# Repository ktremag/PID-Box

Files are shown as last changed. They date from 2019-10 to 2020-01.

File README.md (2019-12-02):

# PID Box Process
## Our Design 
In order to complete our PID box, we wanted to utilize cardboard in order to make a smooth, friction fit device that we could minimize the size of and make into a slim as possible device. 

## Important Information on Design 
In order to make our box out of cardboard, some adjustments were necessary in the design process. 

### Adjustments 
We chose to use single thickness rather than double corregated cardboard. When cutting with cardboard, it is important to remember that the laser cutter will burn off some of the material so the CAD files must be adjusted for this by measuring kerf (or how much the laser cutter takes off) and adding this value to all of the sides to ensure a tight fit on the final box.

We had to keep in mind that the CAD files adjusted with Kerf will not mate together in a Solidworks assembly very smoothly so extra precautions had to be made so that the lack of an accurate assembly didn't result in mis-measured or mis-fit parts. 

### Using the Laser Cutter With Cardboard 
The laser cutter now has a trial cardboard setting under Natural -> Cardboard -> Test. Because cardboard does burn, it creates smoke and needs to be carefully attended during cutting. This smoke/ash also has the ability to collect on the lens so when cutting a lot of cardboard, be even more careful and if you think that too many particles have collectted on the lens, contact Shields or another teacher so that they may remove and clean it. 

### Measuring Kerf
To measure kerf, a small rectange was laser cut out of our desired cardboard and the length measured (l), next we made another cut down the middle of that rectangle, placed the pieces together and measured the new length(l'). Kerf could then be calculated as (l-l'). 

### Friction Fit
Rather than using the traditional T-cuts that are utilized with Acrylic and other hard materials, cardboard is more effective if it is held together using a friction fit design or a design that does not utilize screws to hold the box together and rather the inherent properties of the cardboard. Our box design uses puzzle-piece esq sides with tabs that connect together. We used the configurations tool to make all the separate sides and created the tabs so that they would be the thickness of the cardboard plus kerf. 

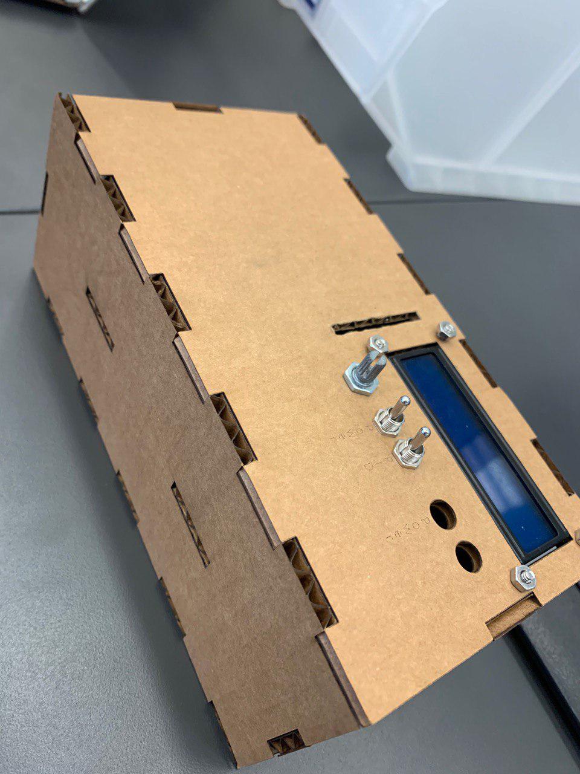
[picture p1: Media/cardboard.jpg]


# PID Box Planning

We will create a box with a spinning wheel powered by a DC motor, an arduino and potentiometer, monitored with a photointerrupter that will display rotations per minute and correct for error using a proportional-integral-derivative controller. Additionally, we would like to minimize wasted materials and use cardboard rather than acrylic as well as a friction fit design. 

## Schedule
We hope to finish this project by December 6th, our weekly milestones and deadlines may be found on our Google Calendar

__Coding and Wiring Process:__ Spin a wheel >> read a wheel speed >> control wheel speed >> implement PID control of wheel speed >> add LEDs, indicators etc. >> Streamline code and wiring

__Solidworks/CAD:__ Determine kerf of cardboard material >> Design box skeleton >> Fricton fit w/ cardboard >> Integrating specific parts/devices >> assemble w/ parts in CAD >> work on actual cardboard etching etc. in order to not look like trash. 

Additionally, we will design/cut a wheel out of acrylic early on in the project so that the code may be fine tuned to the actual goal.

In general, CAD will be up to Frank while coding, wiring and git will be handled by Kit.
## Weekly Milestones

December 6 - Frank: finish updating the midplate & add things for mounting breadboard, Kit: begin to implement PID
December 13 - Frank: finishing touches + motor mount for bok, Kit: calibrate PID and add switches + leds
December 16 - Assemble final and modify for efficiency 

## Criteria and Constraints 
We would like to minimize the total size of our box in order to make it more handheld rather than large and bulky. Additonally, we are attempting a box made of cardboard which complicates the design process somewhat as making cardboard not look unattractive will be an obstacle. Cable/wire placement will likewise need to be managed as minimizing total volume of the box will necessitate more organized wires for functionality.

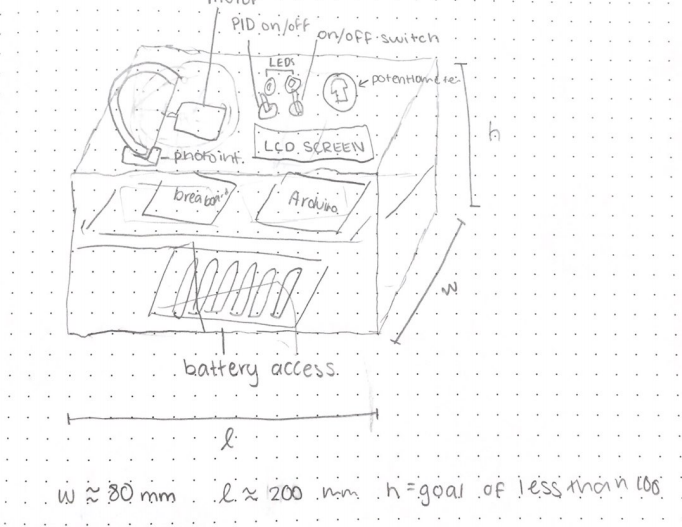
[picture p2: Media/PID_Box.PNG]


## Materials
We expect the necessary materials to be: 
- cardboard for box structure 
- acyrilic wheel
- 3D printed or acrylic breadboard/arduino mount
- battery pack
- arduino uno
- breadboard
- DC motor
- on/off switch
- panel-mounted potentiometer
- LEDs
- LCD screen
- photointerrupter

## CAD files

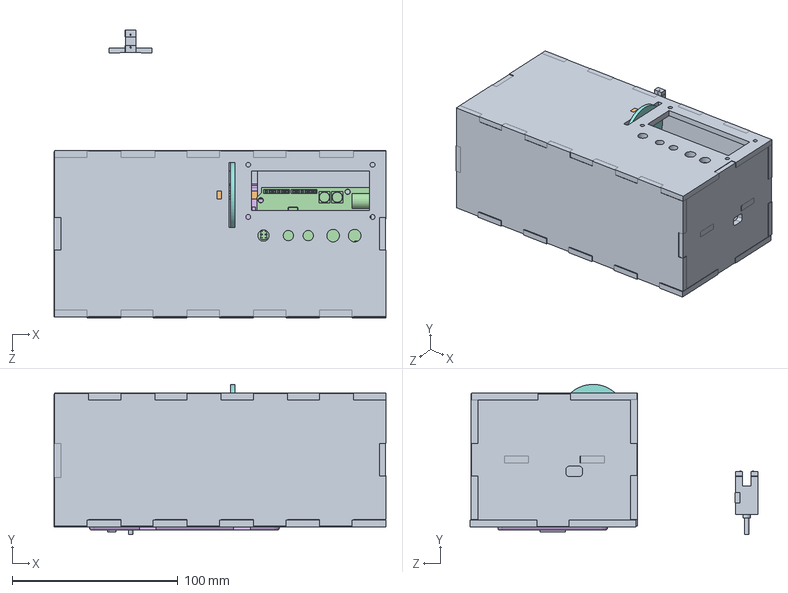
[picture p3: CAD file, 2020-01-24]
CAD/pid_assembly.SLDASM
200.3 x 90.6 x 173.6 mm
PID_box_sides x 7
DC_motor_keyhole_test
breadboard_attachment x 2
ArduinoUno
Half Breadboard
6AA Battery Holder
DCmotor-Size130
Wheel
EE-SX672WR

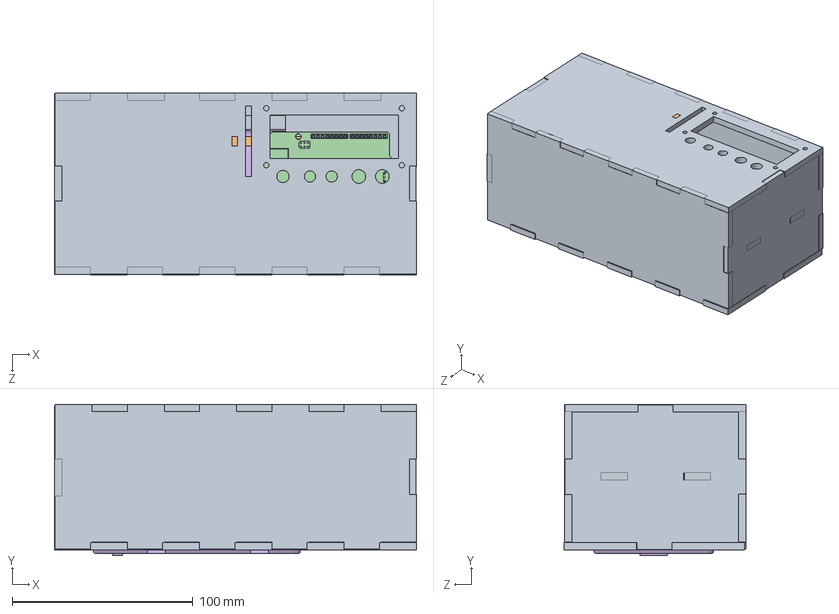
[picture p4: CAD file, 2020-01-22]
CAD/you left your computer on (mrH).SLDASM
200.3 x 83.8 x 101.0 mm
PID_box_sides x 6
DC_motor_keyhole_test
breadboard_attachment x 2
ArduinoUno
Half Breadboard
6AA Battery Holder

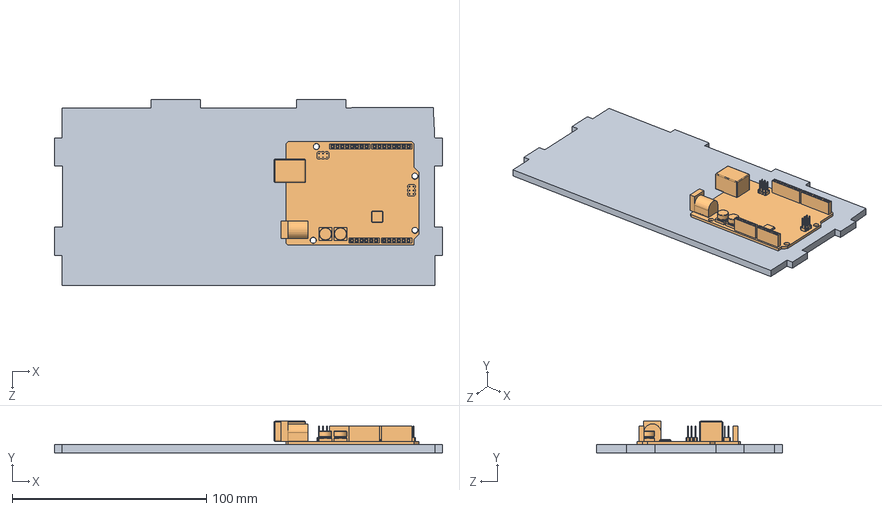
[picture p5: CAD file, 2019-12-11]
CAD/MidPlate_Assem.SLDASM
200.0 x 16.2 x 95.8 mm
PID_box_sides
ArduinoUno

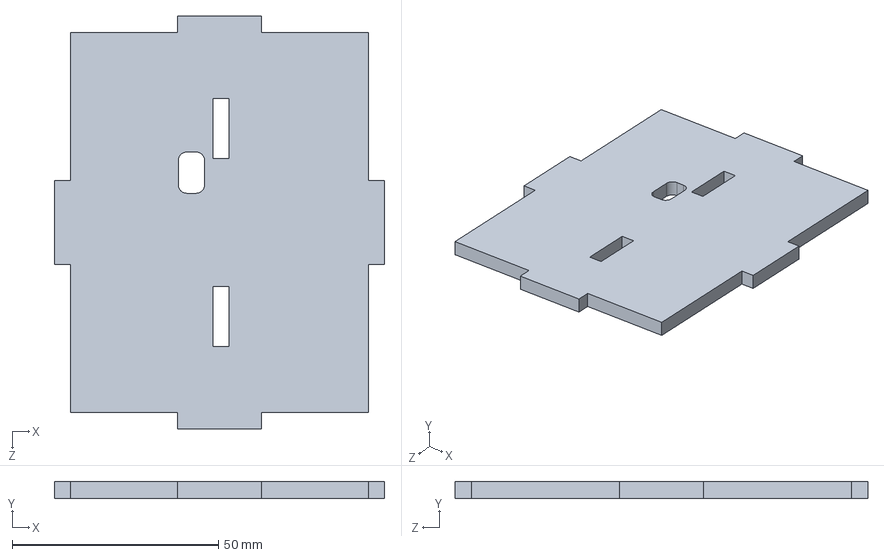
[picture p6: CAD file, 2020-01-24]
CAD/PID_box_sides.SLDPRT
80.0 x 4.15 x 100.0 mm

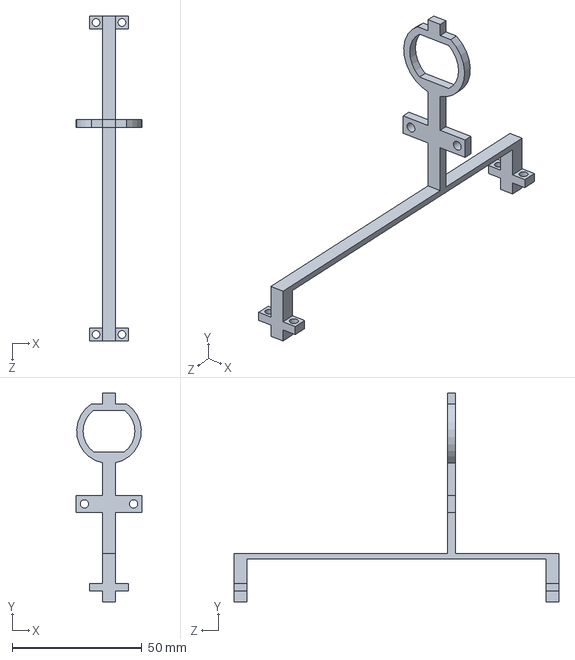
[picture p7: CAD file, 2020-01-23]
CAD/DC_motor_keyhole_test.SLDPRT
25.4 x 80.6 x 125.5 mm

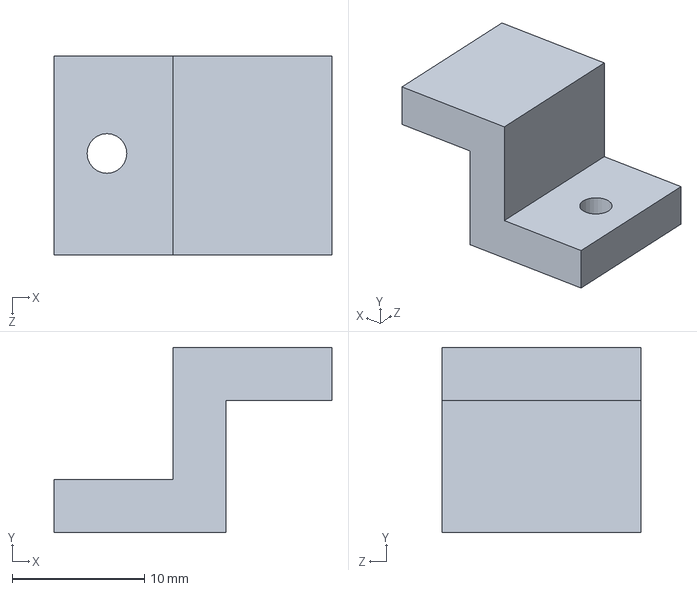
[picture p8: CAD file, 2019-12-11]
CAD/breadboard_attachment.SLDPRT
21.0 x 14.0 x 15.0 mm

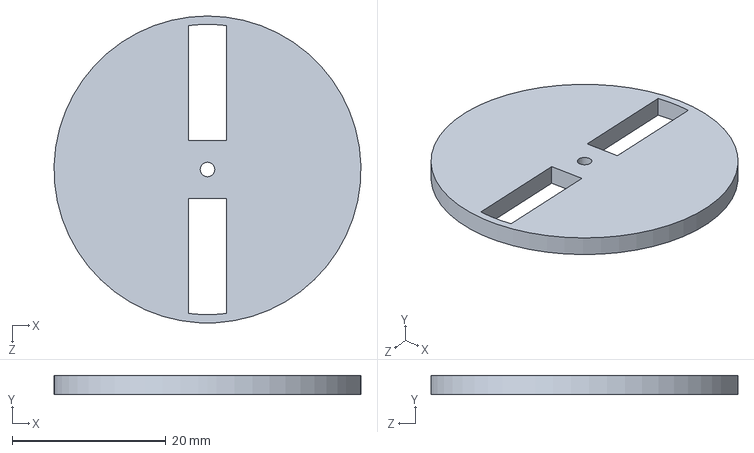
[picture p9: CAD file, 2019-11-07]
CAD/Wheel.SLDPRT
40.0 x 2.50 x 40.0 mm

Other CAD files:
CAD/Fixingswitchholes.SLDDRW
CAD/TopBottomMid.SLDDRW
CAD/Wheelv1.SLDDRW

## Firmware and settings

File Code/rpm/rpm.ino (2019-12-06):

#include <Wire.h>
#include <LiquidCrystal_I2C.h>

LiquidCrystal_I2C lcd(0x27,16,2);	//I2C address of the lcd backpack
int potPin = 3; //potentiometer
int moPin = 9;  //motor
int pintPin1 = 2;  //photo interrupter pin 1
int pintPin2 = 3;

unsigned long int rpm; //rotations per minute
unsigned long time; //time per revolution
unsigned long prev, curr; //previous & current times 
int t = 0;
int count =0;
int calcu = 0;
int Error, Previous_error, Setpoint, Actual;
float Derivative, Drive, Integral;

long int kP = 1;
long int kI = 1;
long int kD = 5;
long int dt = 5;

void setup()
{
  	Serial.begin(9600);

  	//LCD Stuff
	lcd.init();
	lcd.backlight();

	//variables
	rpm = 0;
	time = 0;
	prev = 0; 
  	//PinModes etc.
  	pinMode(potPin, INPUT); //potentiometer = input
  	pinMode(moPin, OUTPUT); //motor = output
  	//pinMode(pintPin1, INPUT_PULLUP);
    	pinMode(pintPin2, INPUT_PULLUP);
  	
  	//Interrupts for photoint
  	attachInterrupt(digitalPinToInterrupt(pintPin2), on, RISING);
  } 
  
void on (){
	count ++;
}

int calcRPM(){
	rpm = (count/2)*300;
	count = 0; 
	prev = curr;  
	return rpm; 
}
void pid(){
      Error = Setpoint - Actual;            
      Integral = Integral + (Error*dt)/10; 
      Derivative = (Error - Previous_error)/dt; 
      Drive = (Error*kP) + (Integral*kI) + (Derivative*kD); 
      Previous_error = Error; 
      t = Setpoint + Drive;
}
void loop()
{

	//motor control
	t = (analogRead(potPin))/4;
	analogWrite(moPin, t);  
	setpoint = t; 
	delay(200);
	//Serial.println(t);

	//timing & RPM
	curr = millis();
	time = curr-prev; 

	//LCD
	lcd.setCursor(0, 0);
	lcd.print("setting" + t);

	//after 5 interrupts, calculate rpm
	if (time >= 200){
		int R = calcRPM();
		Serial.println(R);
		lcd.print("rpm:" + R)
		rpm = actual;
	}
	

} 

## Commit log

2019-11-07 Added CAD files & code draft w/ rpm
    [DC_motor_keyhole.SLDPRT, Wheel.SLDPRT, Wheelv1.SLDDRW]
2019-11-08 PID CAD files
    [PID_box_sides.SLDPRT, pid_assembly.SLDASM]
2019-11-11 somewhat updated to include current process
2019-12-06 added pid function
2019-12-09 Added breadboard piece to edit + 3D print
    [breadboard_attachment.SLDPRT]
2019-12-11 added dimensions to breadboard attachment
    [breadboard_attachment.SLDPRT]
2019-12-11 adding CAD files
    [DC_motor_keyhole.SLDPRT, DC_motor_keyhole_test.SLDPRT, MidPlate_Assem.SLDASM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]
2019-12-16 changed midplate and top positioning
    [DC_motor_keyhole_test.SLDPRT, PID_box_sides.SLDPRT, pid_assembly.SLDASM]
2020-01-22 Adding files with battery and updated mount
    [DC_motor_keyhole_test.SLDPRT, PID_box_sides.SLDPRT, pid_assembly.SLDASM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]
2020-01-23 added wider holes for motor holder
    [DC_motor_keyhole_test.SLDPRT]
2020-01-24 adding port and fixing switches
    [Fixingswitchholes.SLDDRW, PID_box_sides.SLDPRT, pid_assembly.SLDASM]
